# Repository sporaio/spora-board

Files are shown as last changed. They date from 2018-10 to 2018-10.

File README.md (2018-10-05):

# Spora

This is Spora main repository.

## What is Spora?

Spora is the first coin-sized programmable board ready to use and completely open source. It is equipped an accelerometer, magnetometer, gyroscope and environmental temperature sensors. All packed in a coin-shaped board, 18mm (0.724 in) of diameter, with a powerfull MCU and Bluetooth module to transmit the collected data.

It is completely functional and it is ready to use. Its small size makes it ideal for developing a true prototype, closer to your final product with which you can experiment as much as you want before going to the production line.

Combine multiple Spora and let them communicate, to build a full-body wearable to do whatever you want.

Find out more at https://sporaio.com/

## Make it your own

In this repository you'll find all you need to build your own Spora board. Expand it, change it, make it your own.

## Expandable Board

Spora can be programmed and expanded to anything you need. Fitness, sports, motion capture... anything can be achieved with Spora. And to do so we have developed a programmer expansion that is also open source and can be found in this repository: https://github.com/sporaio/spora-programmer-expansion

## Firmware

Find Spora's open source firmware in this repository: https://github.com/sporaio/spora-firmware

## Contributors

This project is open source, under the BSD licence. You can contribute to it and be part of this great community.

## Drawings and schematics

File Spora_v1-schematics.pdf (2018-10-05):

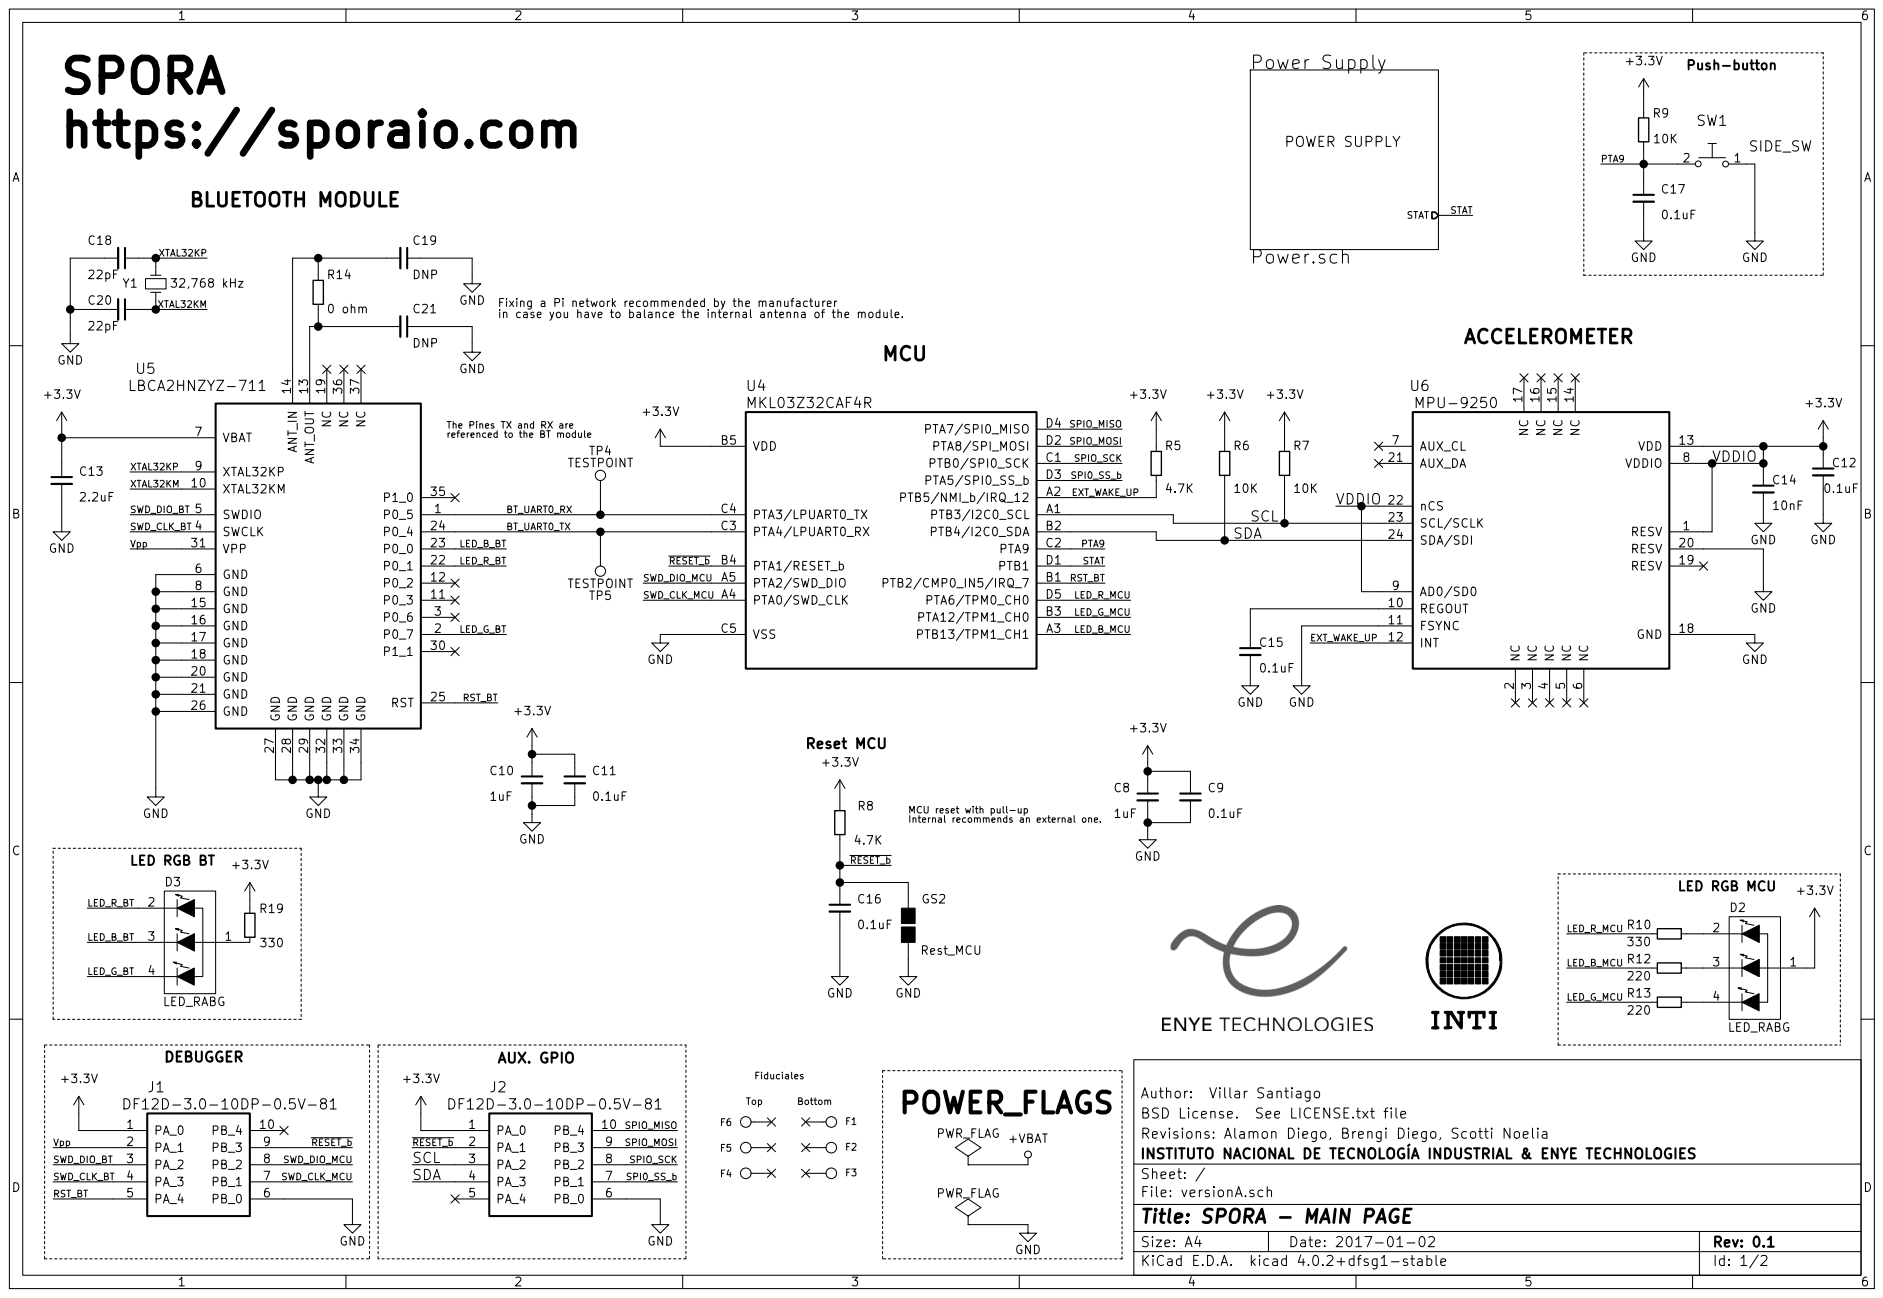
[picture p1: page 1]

The Pines TX and RX are

6 AUX_CL 7 VDDIO 8 AD0/SD0 9 REGOUT 10 RESV 20 FSYNC 11 AUX_DA 21

MCU reset with pull-up

Revisions: Alamon Diego, Brengi Diego, Scotti Noelia BSD License. See LICENSE.txt file Author: Villar Santiago PWR_FLAG

INSTITUTO NACIONAL DE TECNOLOGÍA INDUSTRIAL & ENYE TECHNOLOGIES
File: versionA.sch Sheet: /
Id: 1/2 Title: SPORA - MAIN PAGE

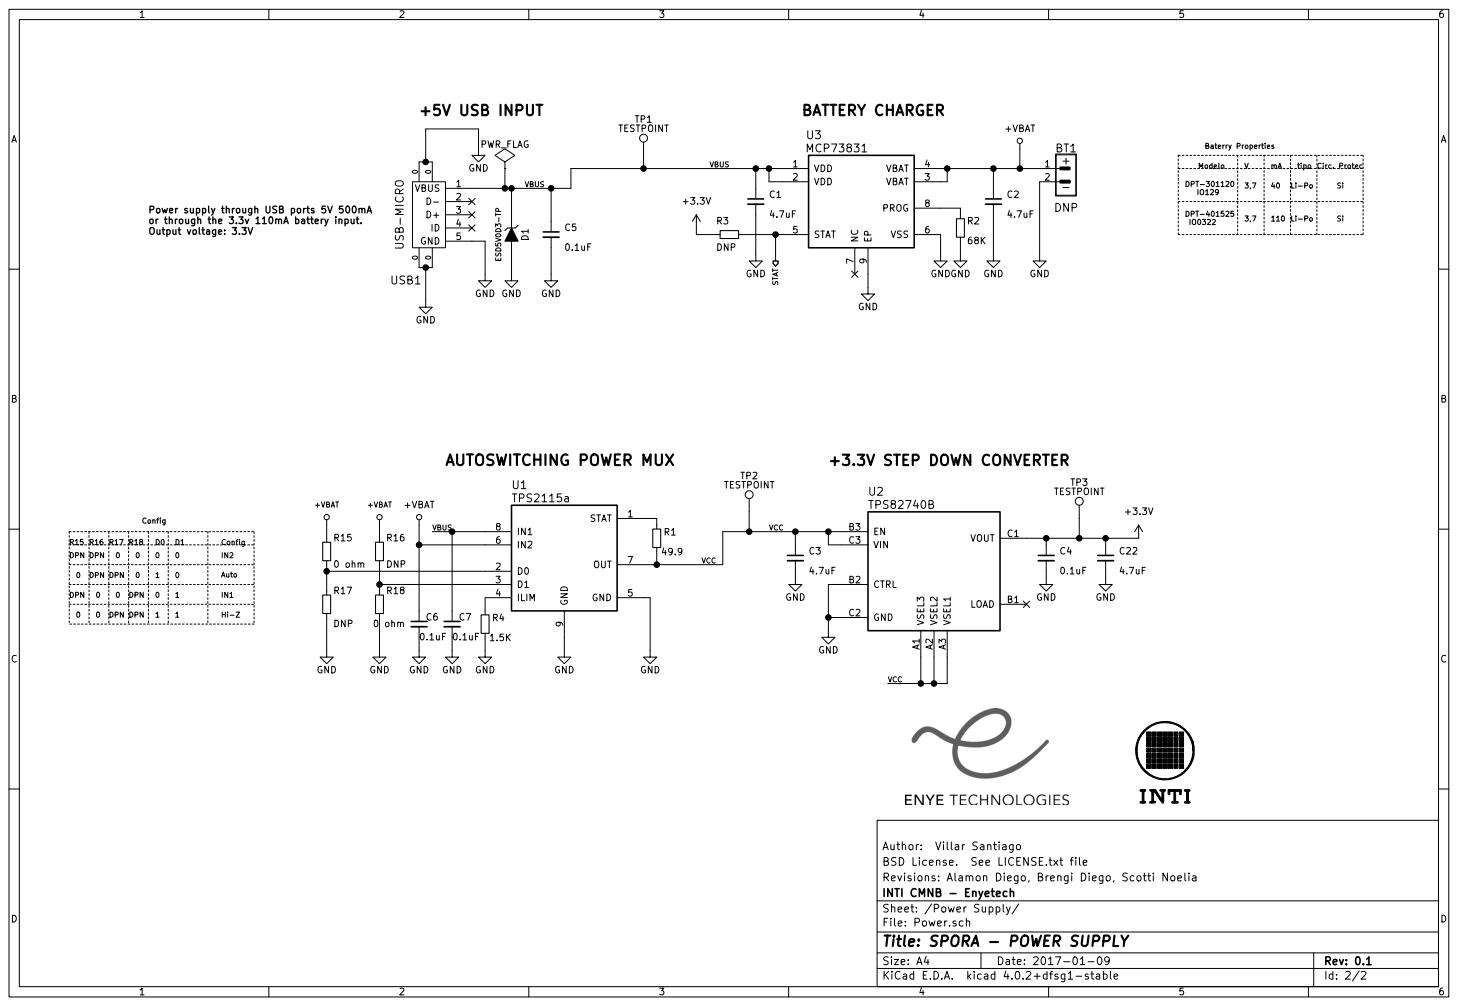
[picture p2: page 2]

Baterry Properties Modelo DPT-301120

Circ. Protec Si Si R15

Li-Po Power supply through USB ports 5V 500mA
or through the 3.3v 110mA battery input.
Output voltage: 3.3V

DPT-401525 IO0322 | 3,7 | 110

VCC AUTOSWITCHING POWER MUX

0 | DPN | 0 DPN | 0 | 1 0 1 | 1 DPN 0 0 | IN2 Auto

Revisions: Alamon Diego, Brengi Diego, Scotti Noelia BSD License. See LICENSE.txt file Author: Villar Santiago GND

INTI CMNB - Enyetech
File: Power.sch Sheet: /Power Supply/
Id: 2/2 Title: SPORA - POWER SUPPLY

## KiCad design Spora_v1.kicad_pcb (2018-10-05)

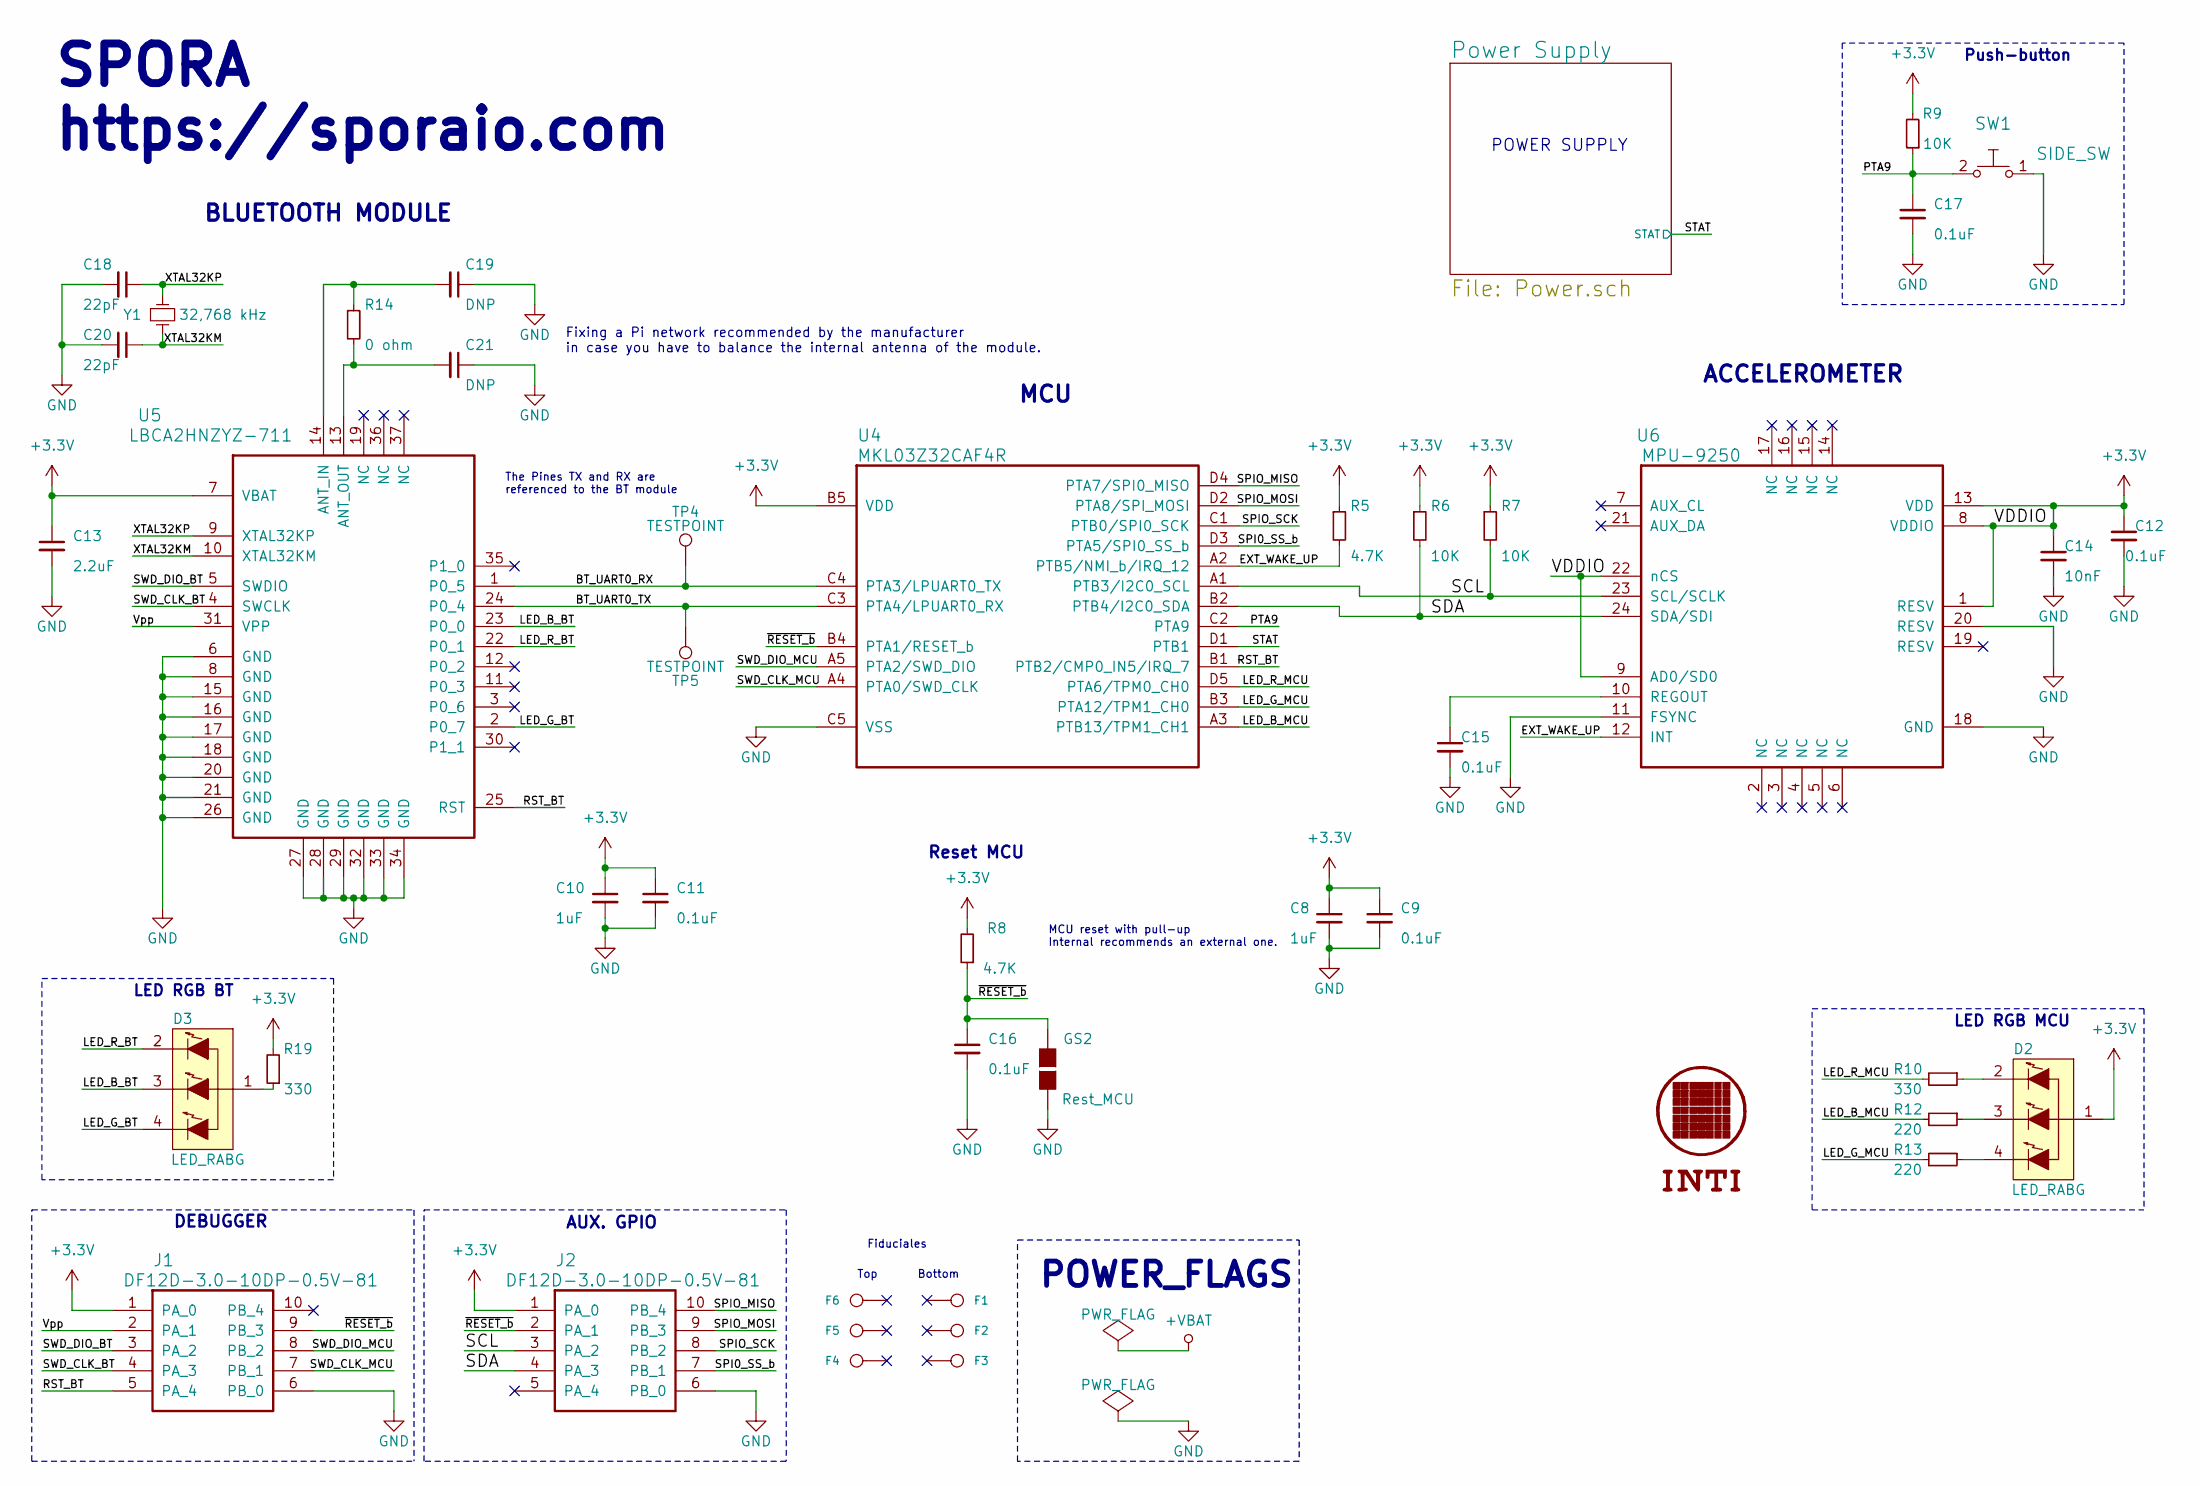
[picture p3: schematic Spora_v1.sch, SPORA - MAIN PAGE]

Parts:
C8, C10: 1uF; c_0201; digikey# 1276-6816-1-ND
C9, C11, C12, C15, C16, C17: 0.1uF; c_0201; digikey# 490-5405-1-ND
C13: 2.2uF; c_0201; digikey# 490-13224-1-ND
C14: 10nF; c_0201; digikey# 490-3166-1-ND
C18, C20: 22pF; c_0402; digikey# 732-7427-1-ND
C19, C21: DNP; c_0402
D2, D3: LED_RABG; SML-LX0404SIUPGUSB; digikey# 67-2125-1-ND
F1, F2, F3, F4, F5, F6: CONN_1; FIDUCIAL_65MIL
G1: LOGO_INTI
GS2: Rest_MCU; GS2
J1, J2: DF12D-3.0-10DP-0.5V-81; df12(3.0)-10dp-0.5v; digikey# H11736CT-ND
R5, R8: 4.7K; r_0201; digikey# 311-4.7KNCT-ND
R6, R7, R9: 10K; r_0201; digikey# 311-10KNCT-ND
R10, R19: 330; r_0201; digikey# 311-330NCT-ND
R12, R13: 220; r_0201; digikey# 311-220NCT-ND
R14: 0 ohm; r_0402; digikey# 311-0.0JRTR-ND
SW1: SIDE_SW; B3U_3000PB; digikey# SW1256DKR-ND
TP4, TP5: TESTPOINT
U4: MKL03Z32CAF4R; mouser# 841-MKL03Z32CAF4R; digikey# MKL03Z32CAF4RTR-ND
U5: LBCA2HNZYZ-711; LBCA2A2HNZYZ-711; digikey# 490-10561-1-ND
U6: MPU-9250; digikey# 1428-1019-1-ND
Y1: 32,768 kHz; ABS05-32.768KHZ-9-T; digikey# 535-11897-1-ND

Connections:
+3V3: C8.1, C9.1, C10.1, C11.1, C12.1, C13.1, C14.1, D2.1 (COMMON_ANODE), J1.1 (PA_0), J2.1 (PA_0), R5.1, R6.1, R7.1, R8.2, R9.2, R19.2, U4.B5 (VDD), U5.7 (VBAT), U6.1 (RESV), U6.8 (VDDIO), U6.9 (AD0/SD0), U6.13 (VDD), U6.22 (nCS); also elsewhere on the board
/BT_UART0_RX: TP4.1, U4.C4 (PTA3/LPUART0_TX), U5.1 (P0_5)
/BT_UART0_TX: TP5.1, U4.C3 (PTA4/LPUART0_RX), U5.24 (P0_4)
/EXT_WAKE_UP: R5.2, U4.A2 (PTB5/NMI_b/IRQ_12), U6.12 (INT)
/LED_B_BT: D3.3 (GREEN_CATHODE), U5.23 (P0_0)
/LED_B_MCU: R12.2, U4.A3 (PTB13/TPM1_CH1)
/LED_G_BT: D3.4 (BLUE_CATHODE), U5.2 (P0_7)
/LED_G_MCU: R13.2, U4.B3 (PTA12/TPM1_CH0)
/LED_R_BT: D3.2 (RED_CATHODE), U5.22 (P0_1)
/LED_R_MCU: R10.2, U4.D5 (PTA6/TPM0_CH0)
/PTA9: C17.1, R9.1, SW1.2, U4.C2 (PTA9)
/Power Supply/STAT: U4.D1 (PTB1); also elsewhere on the board
/RST_BT: J1.5 (PA_4), U4.B1 (PTB2/CMP0_IN5/IRQ_7), U5.25 (RST)
/SCL: J2.3 (PA_2), R7.2, U4.A1 (PTB3/I2C0_SCL), U6.23 (SCL/SCLK)
/SDA: J2.4 (PA_3), R6.2, U4.B2 (PTB4/I2C0_SDA), U6.24 (SDA/SDI)
/SPI0_SS_b: J2.7 (PB_1), U4.D3 (PTA5/SPI0_SS_b)
/SPIO_MISO: J2.10 (PB_4), U4.D4 (PTA7/SPI0_MISO)
/SPIO_MOSI: J2.9 (PB_3), U4.D2 (PTA8/SPI_MOSI)
/SPIO_SCK: J2.8 (PB_2), U4.C1 (PTB0/SPI0_SCK)
/SWD_CLK_BT: J1.4 (PA_3), U5.4 (SWCLK)
/SWD_CLK_MCU: J1.7 (PB_1), U4.A4 (PTA0/SWD_CLK)
/SWD_DIO_BT: J1.3 (PA_2), U5.5 (SWDIO)
/SWD_DIO_MCU: J1.8 (PB_2), U4.A5 (PTA2/SWD_DIO)
/Vpp: J1.2 (PA_1), U5.31 (VPP)
/XTAL32KM: C20.1, U5.10 (XTAL32KM), Y1.2
/XTAL32KP: C18.1, U5.9 (XTAL32KP), Y1.1
/~RESET_b: C16.1, GS2.1 (G1), J1.9 (PB_3), J2.2 (PA_1), R8.1, U4.B4 (PTA1/RESET_b)
GND: C8.2, C9.2, C10.2, C11.2, C12.2, C13.2, C14.2, C15.2, C16.2, C17.2, C18.2, C19.1, C20.2, C21.1, GS2.2 (G2), J1.6 (PB_0), J2.6 (PB_0), SW1.1, U4.C5 (VSS), U5.6 (GND), U5.8 (GND), U5.15 (GND), U5.16 (GND), U5.17 (GND), U5.18 (GND), U5.20 (GND), U5.21 (GND), U5.26 (GND), U5.27 (GND), U5.28 (GND), U5.29 (GND), U5.32 (GND), U5.33 (GND), U5.34 (GND), U6.11 (FSYNC), U6.18 (GND), U6.20 (RESV); also elsewhere on the board
unnamed: C15.1, U6.10 (REGOUT)
unnamed: C19.2, R14.1, U5.14 (ANT_IN)
unnamed: C21.2, R14.2, U5.13 (ANT_OUT)
unnamed: D2.2 (RED_CATHODE), R10.1
unnamed: D2.3 (GREEN_CATHODE), R12.1
unnamed: D2.4 (BLUE_CATHODE), R13.1
unnamed: D3.1 (COMMON_ANODE), R19.1

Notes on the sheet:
POWER_FLAGS
AUX. GPIO
Reset MCU
LED RGB MCU
Push-button
DEBUGGER
The Pines TX and RX are referenced to the BT module
MCU
ACCELEROMETER
BLUETOOTH MODULE
MCU reset with pull-up Internal recommends an external one.
Fixing a Pi network recommended by the manufacturer in case you have to balance the internal antenna of the module.
POWER SUPPLY
SPORA https://sporaio.com
LED RGB BT
Fiduciales
Top
Bottom

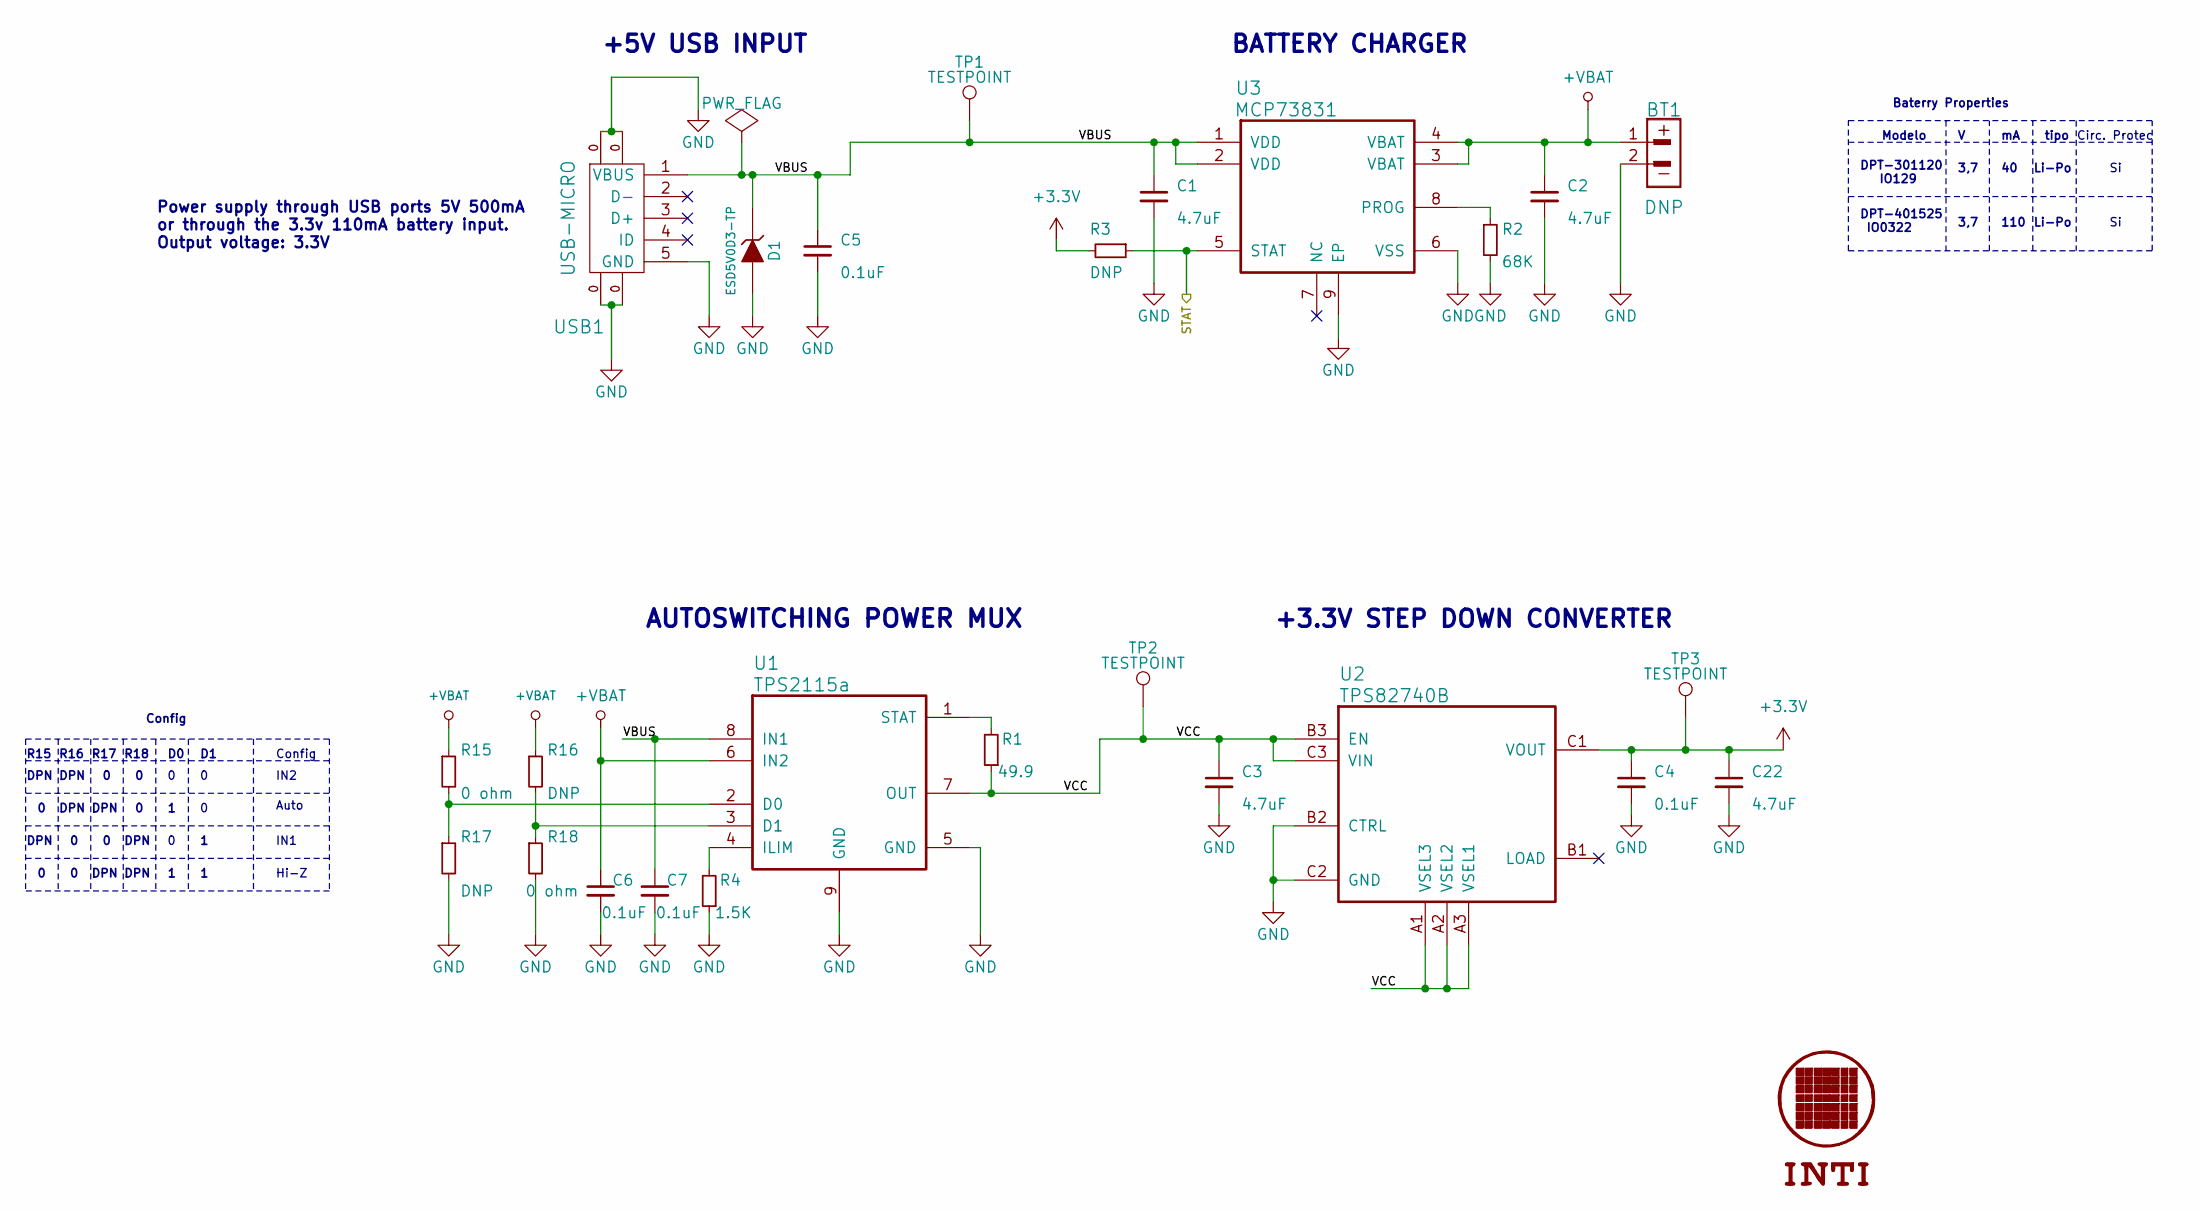
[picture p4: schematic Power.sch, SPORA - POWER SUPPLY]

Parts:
BT1: DNP; BAT_CON
C1, C2, C3, C22: 4.7uF; c_0201; digikey# 490-13230-1-ND
C4, C5, C6, C7: 0.1uF; c_0201; digikey# 490-5405-1-ND
D1: ESD5V0D3-TP; SOD-323; digikey# ESD5V0D3-TPMSCT-ND
G2: LOGO_INTI
R1: 49.9; r_0201; digikey# P49.9ABCT-ND
R2: 68K; r_0201; digikey# P68.0KABCT-ND
R3: DNP; r_0201; digikey# 311-470NCT-ND
R4: 1.5K; r_0201; digikey# 311-1.5KNCT-ND
R15, R18: 0 ohm; r_0402; digikey# 311-0.0JRCT-ND
R16, R17: DNP; r_0402
TP1, TP2, TP3: TESTPOINT
U1: TPS2115a; TPS2115A; digikey# 296-23394-1-ND
U2: TPS82740B; digikey# 296-37973-1-ND
U3: MCP73831; MCP73821; digikey# MCP73831-2ACI/MC-ND
USB1: USB-MICRO; conn_usb_B_micro_smd; digikey# H125279CT-ND

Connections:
+3V3: C4.1, C22.1, R3.2, TP3.1, U2.C1 (VOUT); also elsewhere on the board
+VBAT: BT1.1, C2.1, C6.1, R15.1, R16.1, U1.6 (IN2), U3.3 (VBAT), U3.4 (VBAT)
/Power Supply/STAT: R3.1, U3.5 (STAT); also elsewhere on the board
/Power Supply/VBUS: C1.1, C5.1, C7.1, D1.1 (K), TP1.1, U1.8 (IN1), U3.1 (VDD), U3.2 (VDD), USB1.1 (VBUS)
/Power Supply/VCC: C3.1, R1.1, TP2.1, U1.7 (OUT), U2.A1 (VSEL3), U2.A2 (VSEL2), U2.A3 (VSEL1), U2.B3 (EN), U2.C3 (VIN)
GND: BT1.2, C1.2, C2.2, C3.2, C4.2, C5.2, C6.2, C7.2, C22.2, D1.2 (A), R2.2, R4.1, R17.2, R18.2, U1.5 (GND), U1.9 (GND), U2.B2 (CTRL), U2.C2 (GND), U3.6 (VSS), U3.9 (EP), USB1.0, USB1.5 (GND); also elsewhere on the board
unnamed: R1.2, U1.1 (STAT)
unnamed: R2.1, U3.8 (PROG)
unnamed: R4.2, U1.4 (ILIM)
unnamed: R15.2, R17.1, U1.2 (D0)
unnamed: R16.2, R18.1, U1.3 (D1)

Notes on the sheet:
+3.3V STEP DOWN CONVERTER
AUTOSWITCHING POWER MUX
BATTERY CHARGER
+5V USB INPUT
Baterry Properties
Modelo
DPT-301120 IO129
DPT-401525 IO0322
3,7
110
tipo
Li-Po
Power supply through USB ports 5V 500mA or through the 3.3v 110mA battery input. Output voltage: 3.3V
Circ. Protec
Config
R15
R16
DPN
Config
R17
R18
Auto
IN2
IN1
Hi-Z

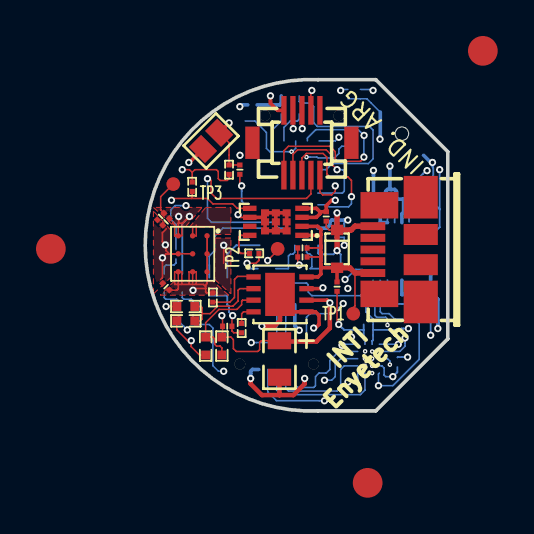
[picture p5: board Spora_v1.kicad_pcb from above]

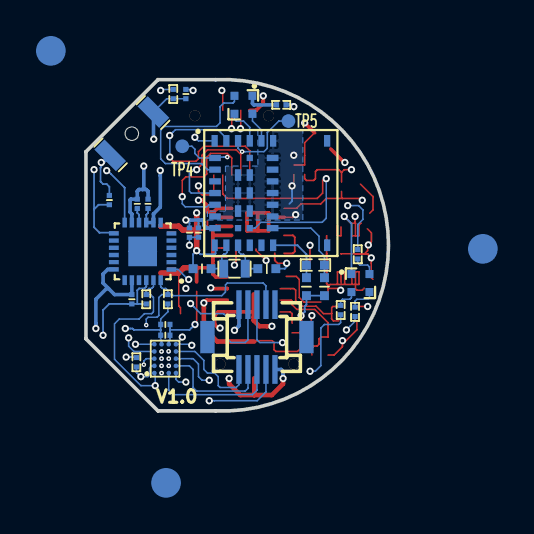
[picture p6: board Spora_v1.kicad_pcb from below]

Board: 6 copper layers, 16.8 x 18.4 mm, 67 parts (35 on the bottom side), 43 nets.
